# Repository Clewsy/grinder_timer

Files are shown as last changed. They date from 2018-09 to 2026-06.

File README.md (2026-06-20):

# grinder_timer

## Rev2.1

Modelled and printed a bezel for the OLED to tidy-up the enclosure.  Modelled in [freecad][link_web_freecad], printed on a [Prusa CORE One+][link_web_prusa].  CAD files and photo [here][link_repo_bezel].

## Rev2

More information can be found at my [project page][link_clews_grinder_timer_rev2].

Improvements since rev1:

- Hardware:
	- [X] Pull-ups on I2C SDA and CLK lines.
	- [X] Drive relay with a transistor instead of direct from IO.
	- [X] Add flyback diode protection to relay coil.
	- [X] Smaller transformer.
	- [X] Smaller relay.
	- [X] Switch to SMD where possible.
	- [X] Two-sided PCB (have it fabricated instead of etching).
	- [X] Switch buttons from mushy panel-mount to tactile SMD.
	- [X] Balanced caps for the 32.768kHz crystal.
	- [X] Put grind button LED on a PWM output.
- Firmware:
	- [X] Switch from C to C++.
	- [X] New OLED driver (change from SPI SSD1306 to I2C SH1106 controller).
	- [X] Pulse/fade effect for grind button LED.
	- [X] Ability to cancel a grind once started.
	- [X] Remember selected preset after a power-cycle.

Repo contents:
- [data][link_repo_data]: Datasheets and specs for the various components used.
- [firmware][link_repo_firmware]: The code witten in C++ and developed in VSCode with the PlatformIO IDE.
- [hardware][link_repo_hardware]: KiCad files including the [schematic][link_repo_schematic] and PCB layout.
- [rev1_archive][link_repo_rev1_archive]: Firmware developed for the original grinder_timer (written in C).

Note: I used an ATmega328PB which isn't supported by the latest avr-libc package.  For the code in this repo to compile, using the included makefile, options are:
a) Modify to use an ATmega328; or
b) Manually install the *libatmega328pb.a*, *iom328pb.h* and *crtatmega328pb.o* files; or
c) Use platformio instead of the makefile.

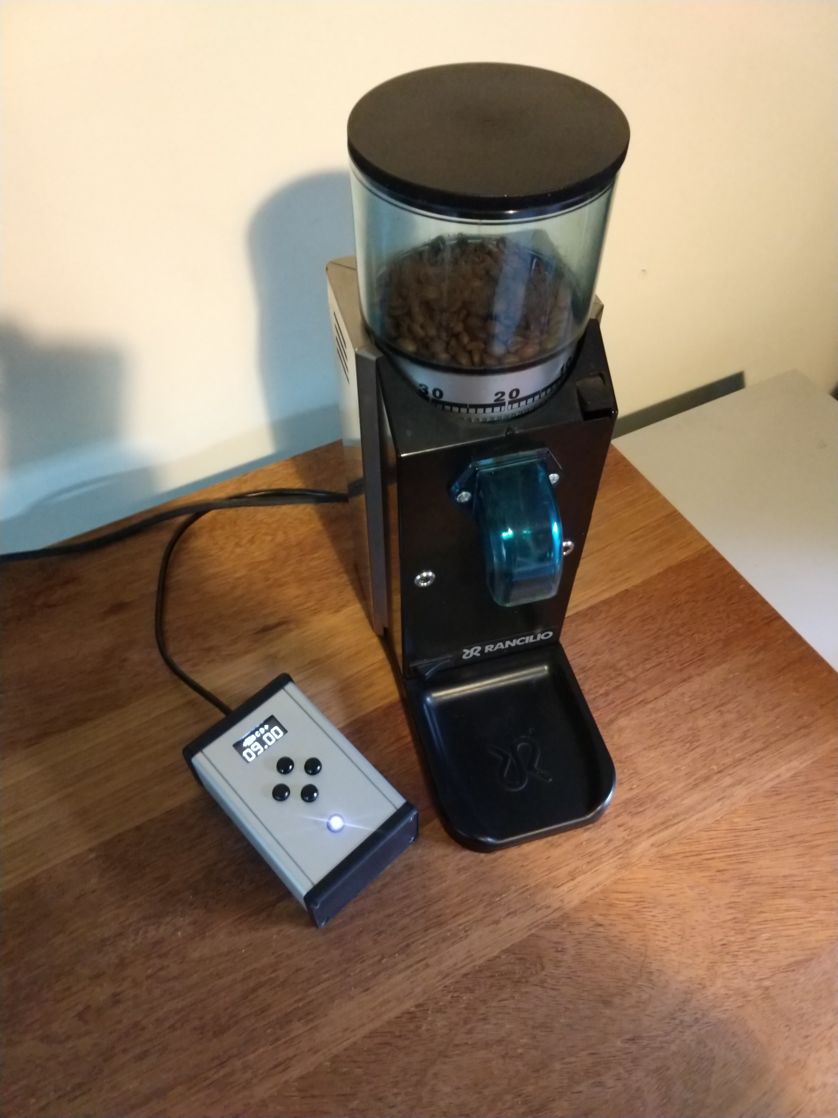
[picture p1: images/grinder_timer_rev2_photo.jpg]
The completed grinder_timer_rev2.

---

## Rev1

This is a programmable timer tethered to a [Rancilio Rocky][link_web_rancilio_rocky] coffee grinder. The Rocky is a "dumb" grinder and electrically very simple. Basically it's an ac motor with an on/off switch and a momentary push-button to grind. This project adds an electronic timer so that repeatable grind quantities can be produced without having to stand over the grinder. Features:
- Four programmable presets (A, B, C or D) stored in EEPROM to survive powercycle.
- Left/Right buttons to select preset.
- Up/Down buttons to adjust grind duration for selected preset (0.25s increments up to 60s).
- Grind button to initiate grind and begin countdown timer.
- Oled display (128x64) to show preset menu and countdown timer.
- Aluminium enclosure.
- Single cable (3-core) tether to grinder for power and control.

The code, schematic and PCB layout are all included here on gitlab.  More information can be found at my [project page][link_clews_grinder_timer].

Proudly mentioned at [hackaday.com][link_web_hackaday_grinder_timer].

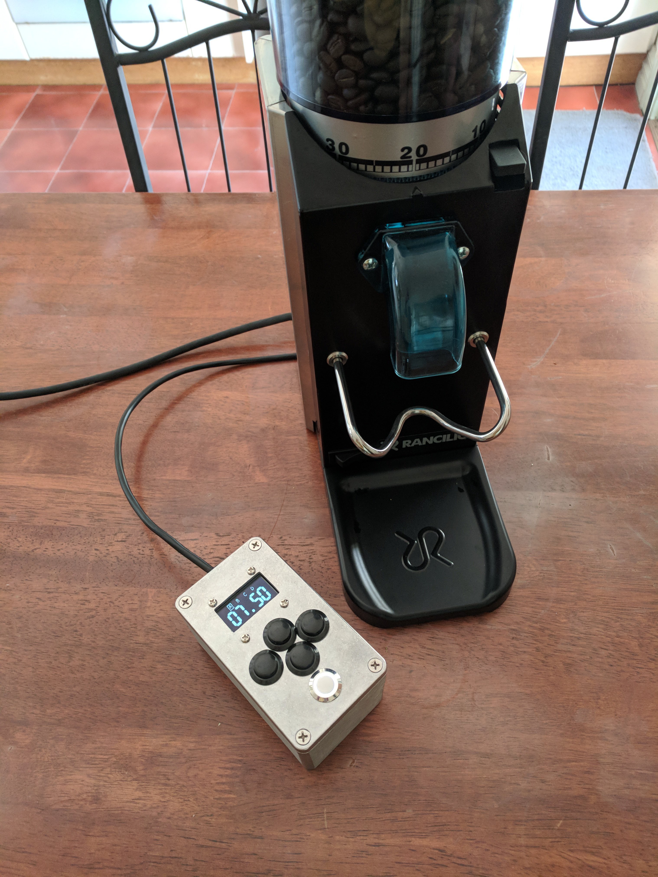
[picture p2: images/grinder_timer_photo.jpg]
The completed grinder_timer.


[link_clews_grinder_timer]:https://clews.pro/projects/grinder_timer.php
[link_clews_grinder_timer_rev2]:https://clews.pro/projects/grinder_timer_rev2.php

[link_repo_bezel]:hardware/bezel/
[link_repo_data]:data/
[link_repo_firmware]:firmware/
[link_repo_hardware]:hardware/pcb/
[link_repo_rev1_archive]:rev1_archive/
[link_repo_schematic]:hardware/schematic.pdf

[link_web_freecad]:https://www.freecad.org/
[link_web_hackaday_grinder_timer]:https://hackaday.com/2017/12/14/dumb-coffee-grinder-gets-smarter-with-time/
[link_web_prusa]:https://www.prusa3d.com/
[link_web_rancilio_rocky]:https://www.ranciliogroup.com/rancilio/rocky/rocky/

[image_grinder_timer]:images/grinder_timer_photo.jpg
[image_grinder_timer_rev2]:images/grinder_timer_rev2_photo.jpg

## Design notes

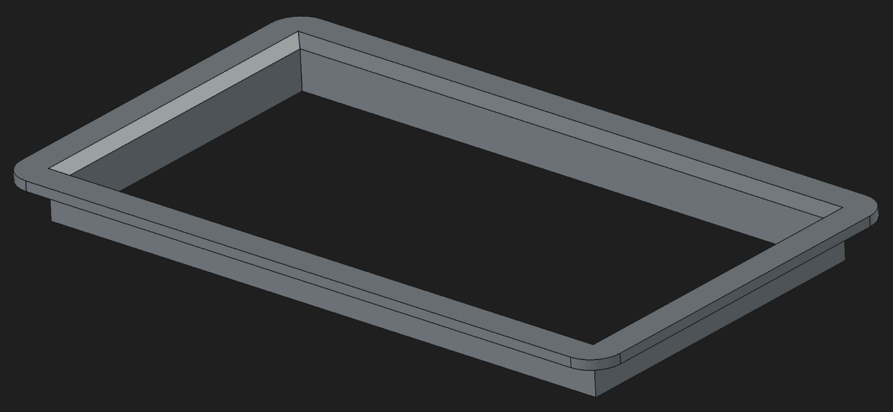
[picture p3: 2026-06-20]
hardware/bezel/grinder_timer_bezel_model.png

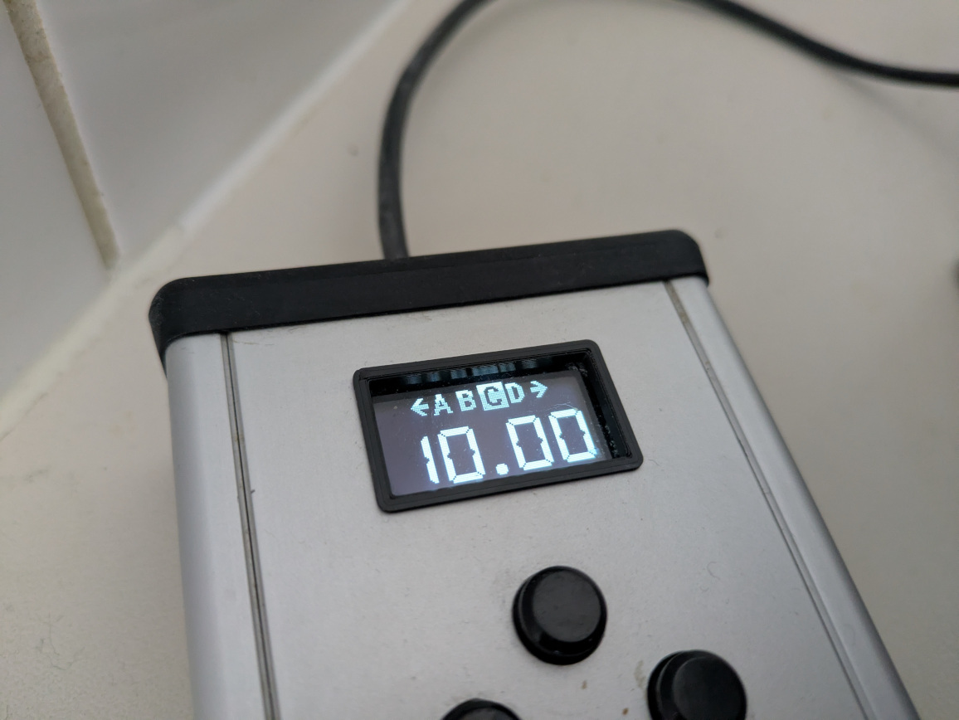
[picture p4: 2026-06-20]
hardware/bezel/grinder_timer_bezel.jpg

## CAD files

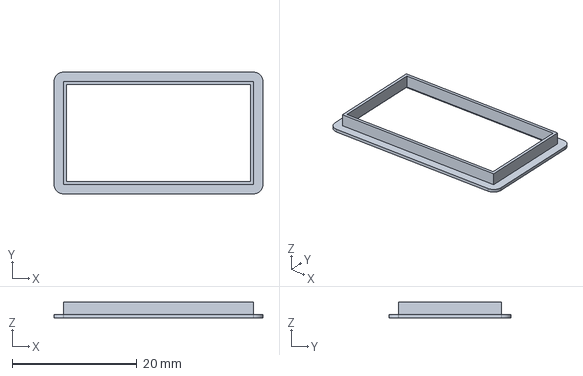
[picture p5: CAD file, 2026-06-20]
hardware/bezel/grinder_timer_bezel.FCStd
33.5 x 19.5 x 2.50 mm

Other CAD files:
hardware/bezel/grinder_timer_bezel.stl

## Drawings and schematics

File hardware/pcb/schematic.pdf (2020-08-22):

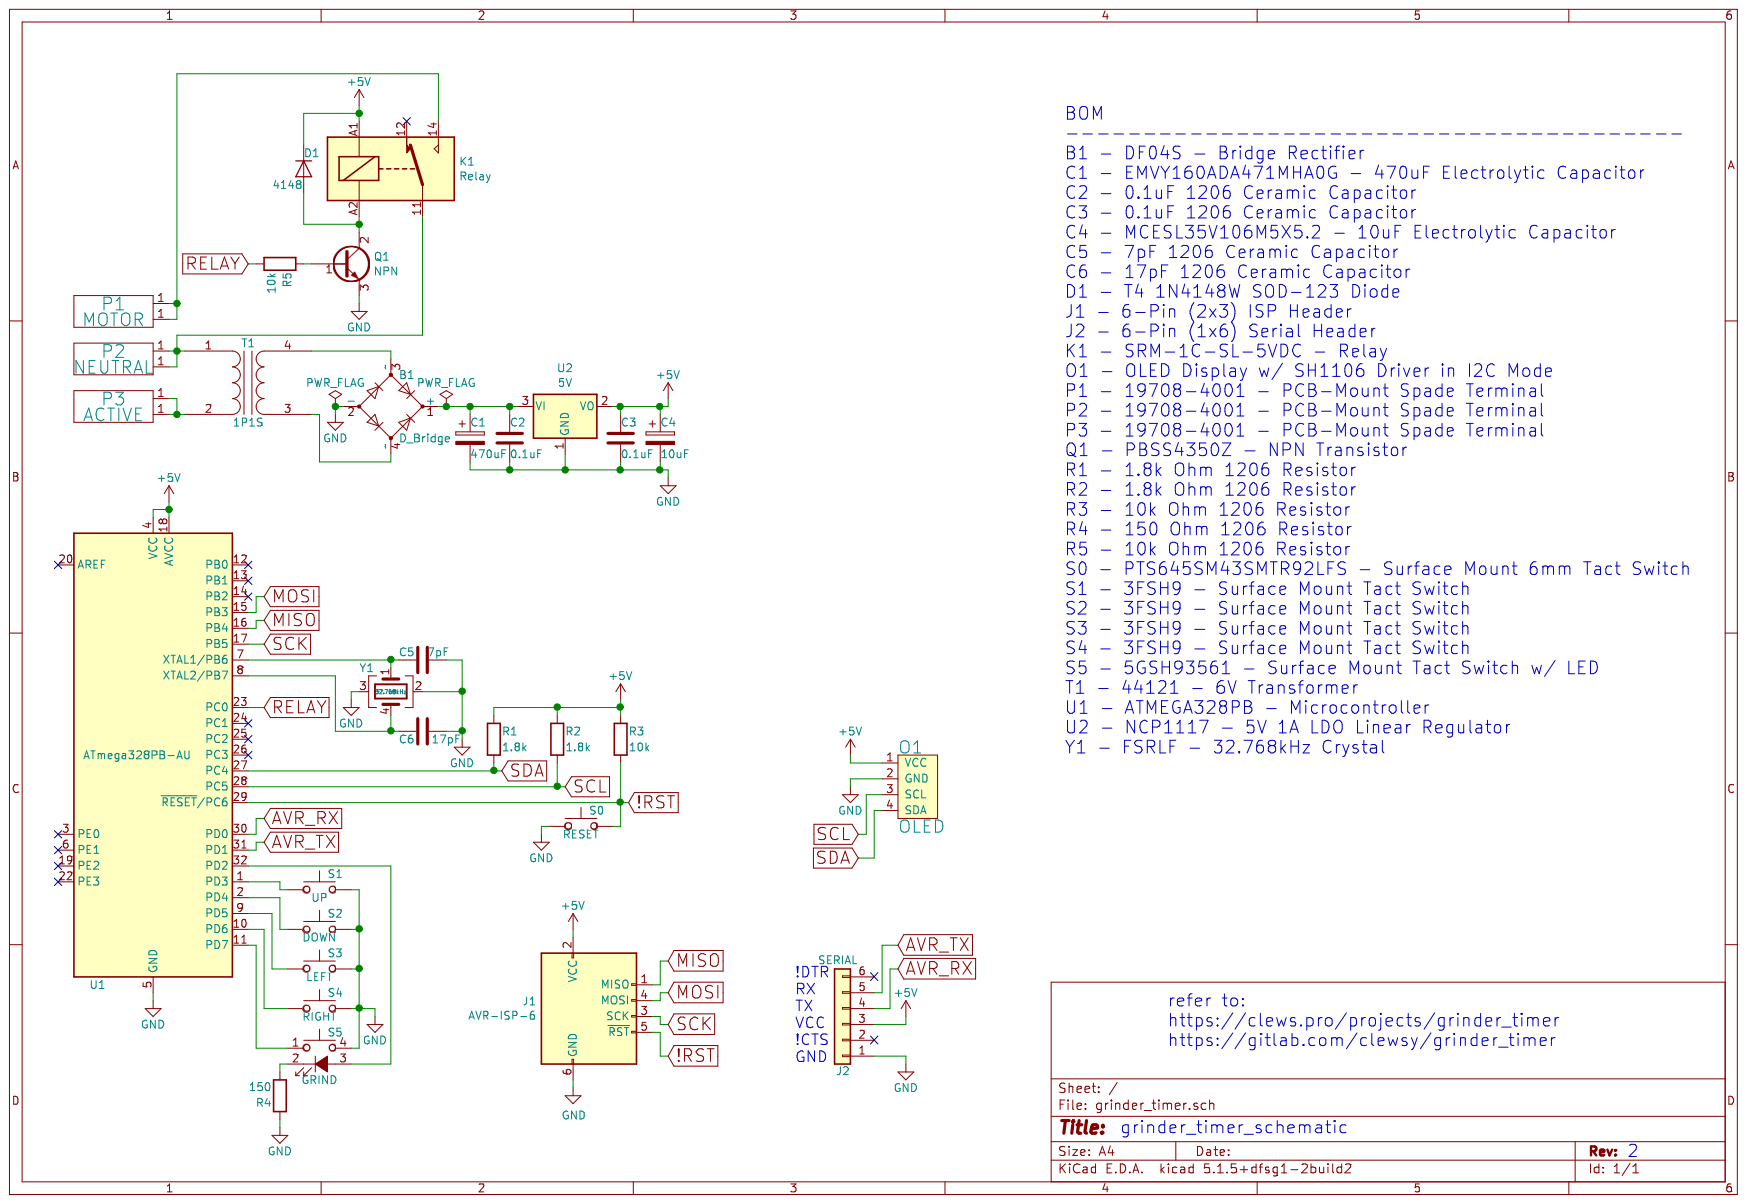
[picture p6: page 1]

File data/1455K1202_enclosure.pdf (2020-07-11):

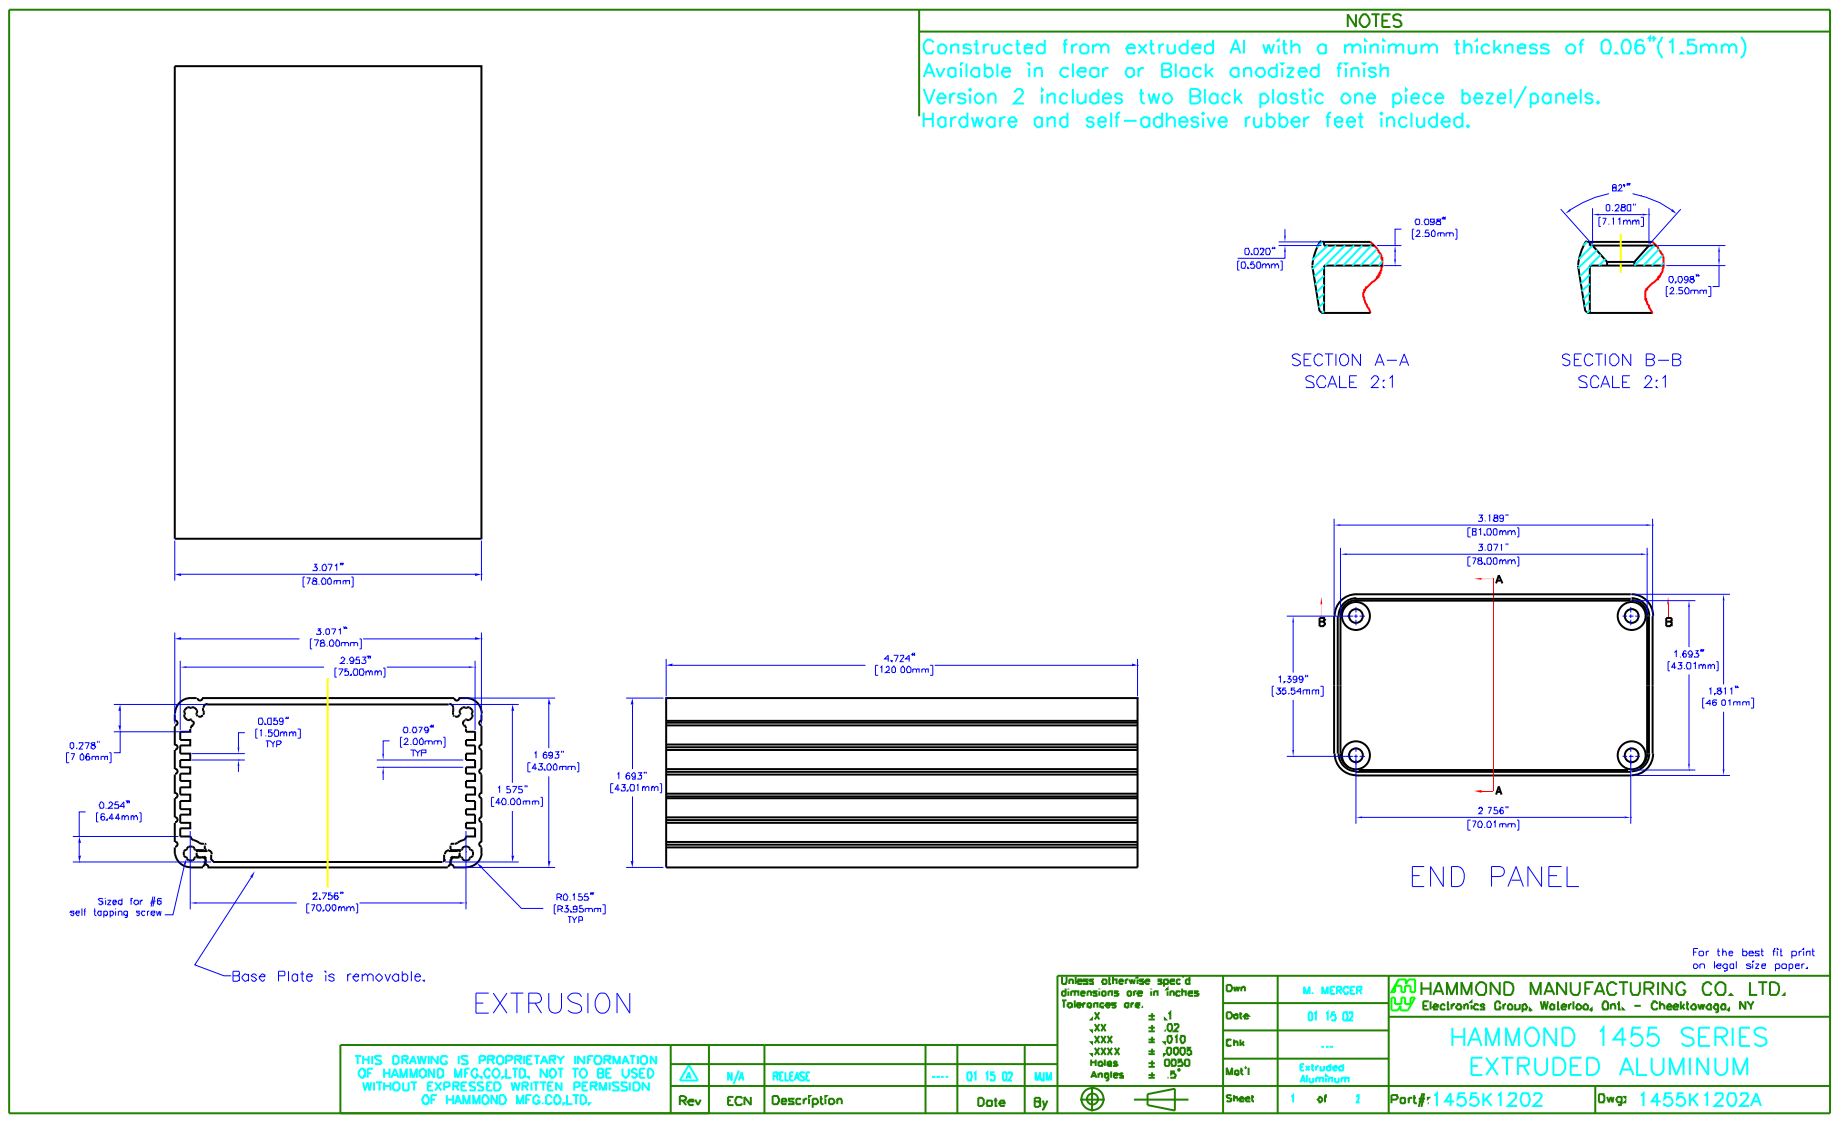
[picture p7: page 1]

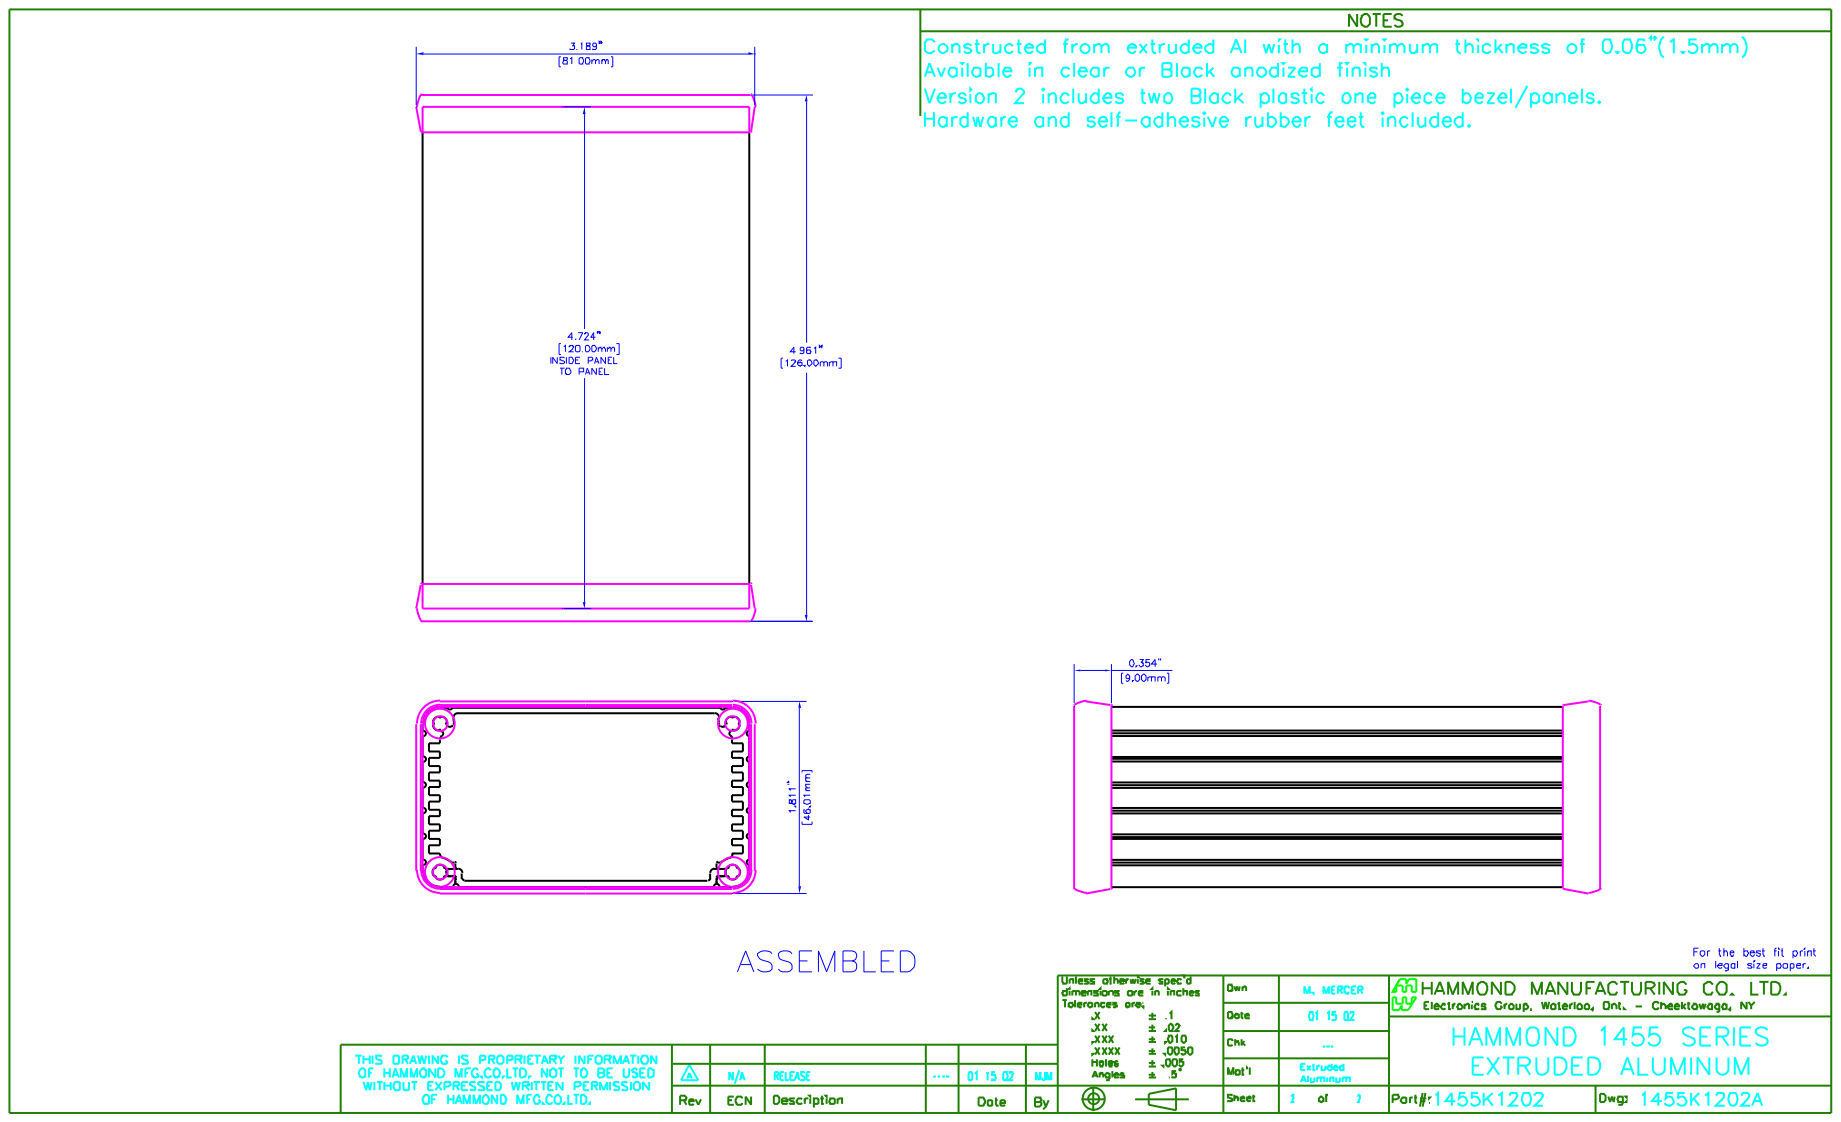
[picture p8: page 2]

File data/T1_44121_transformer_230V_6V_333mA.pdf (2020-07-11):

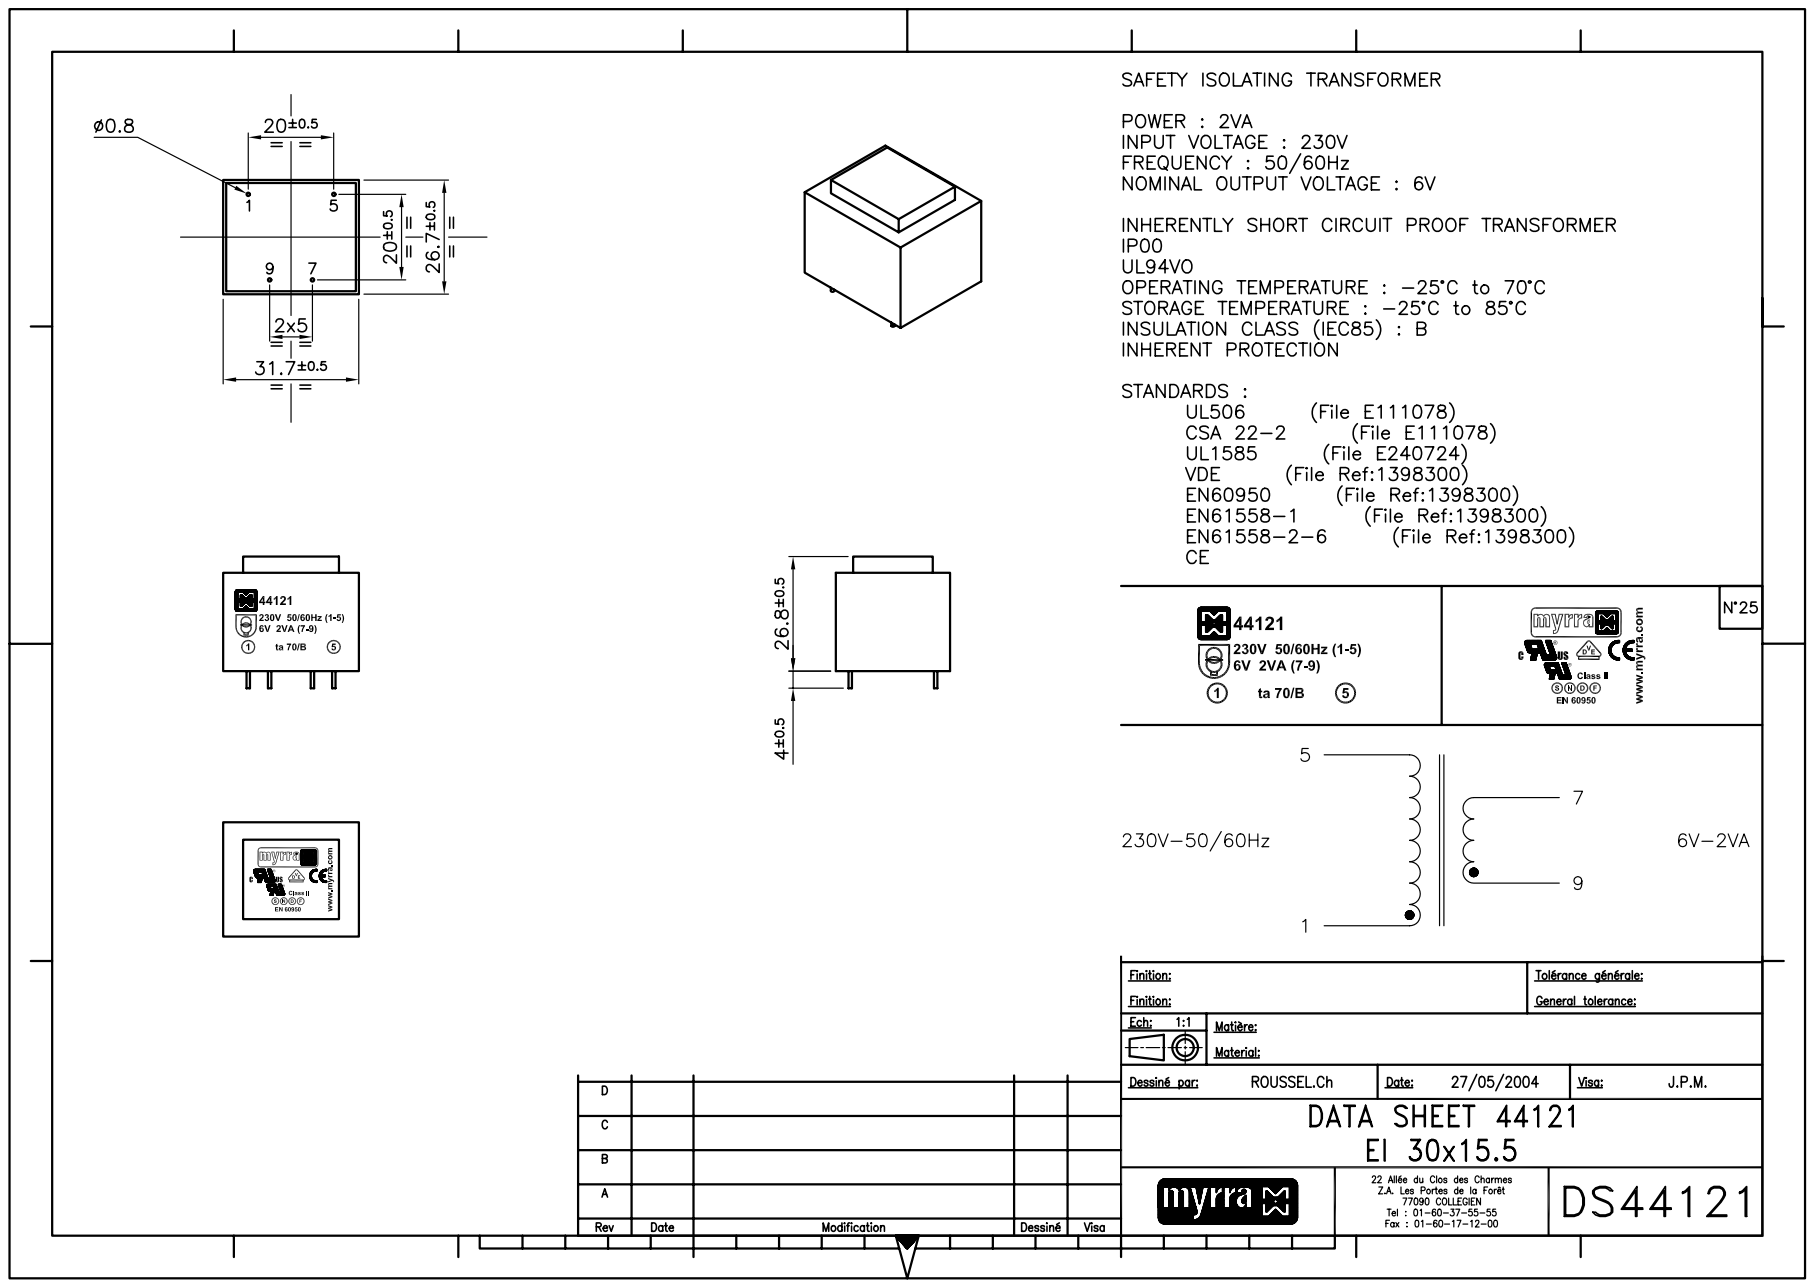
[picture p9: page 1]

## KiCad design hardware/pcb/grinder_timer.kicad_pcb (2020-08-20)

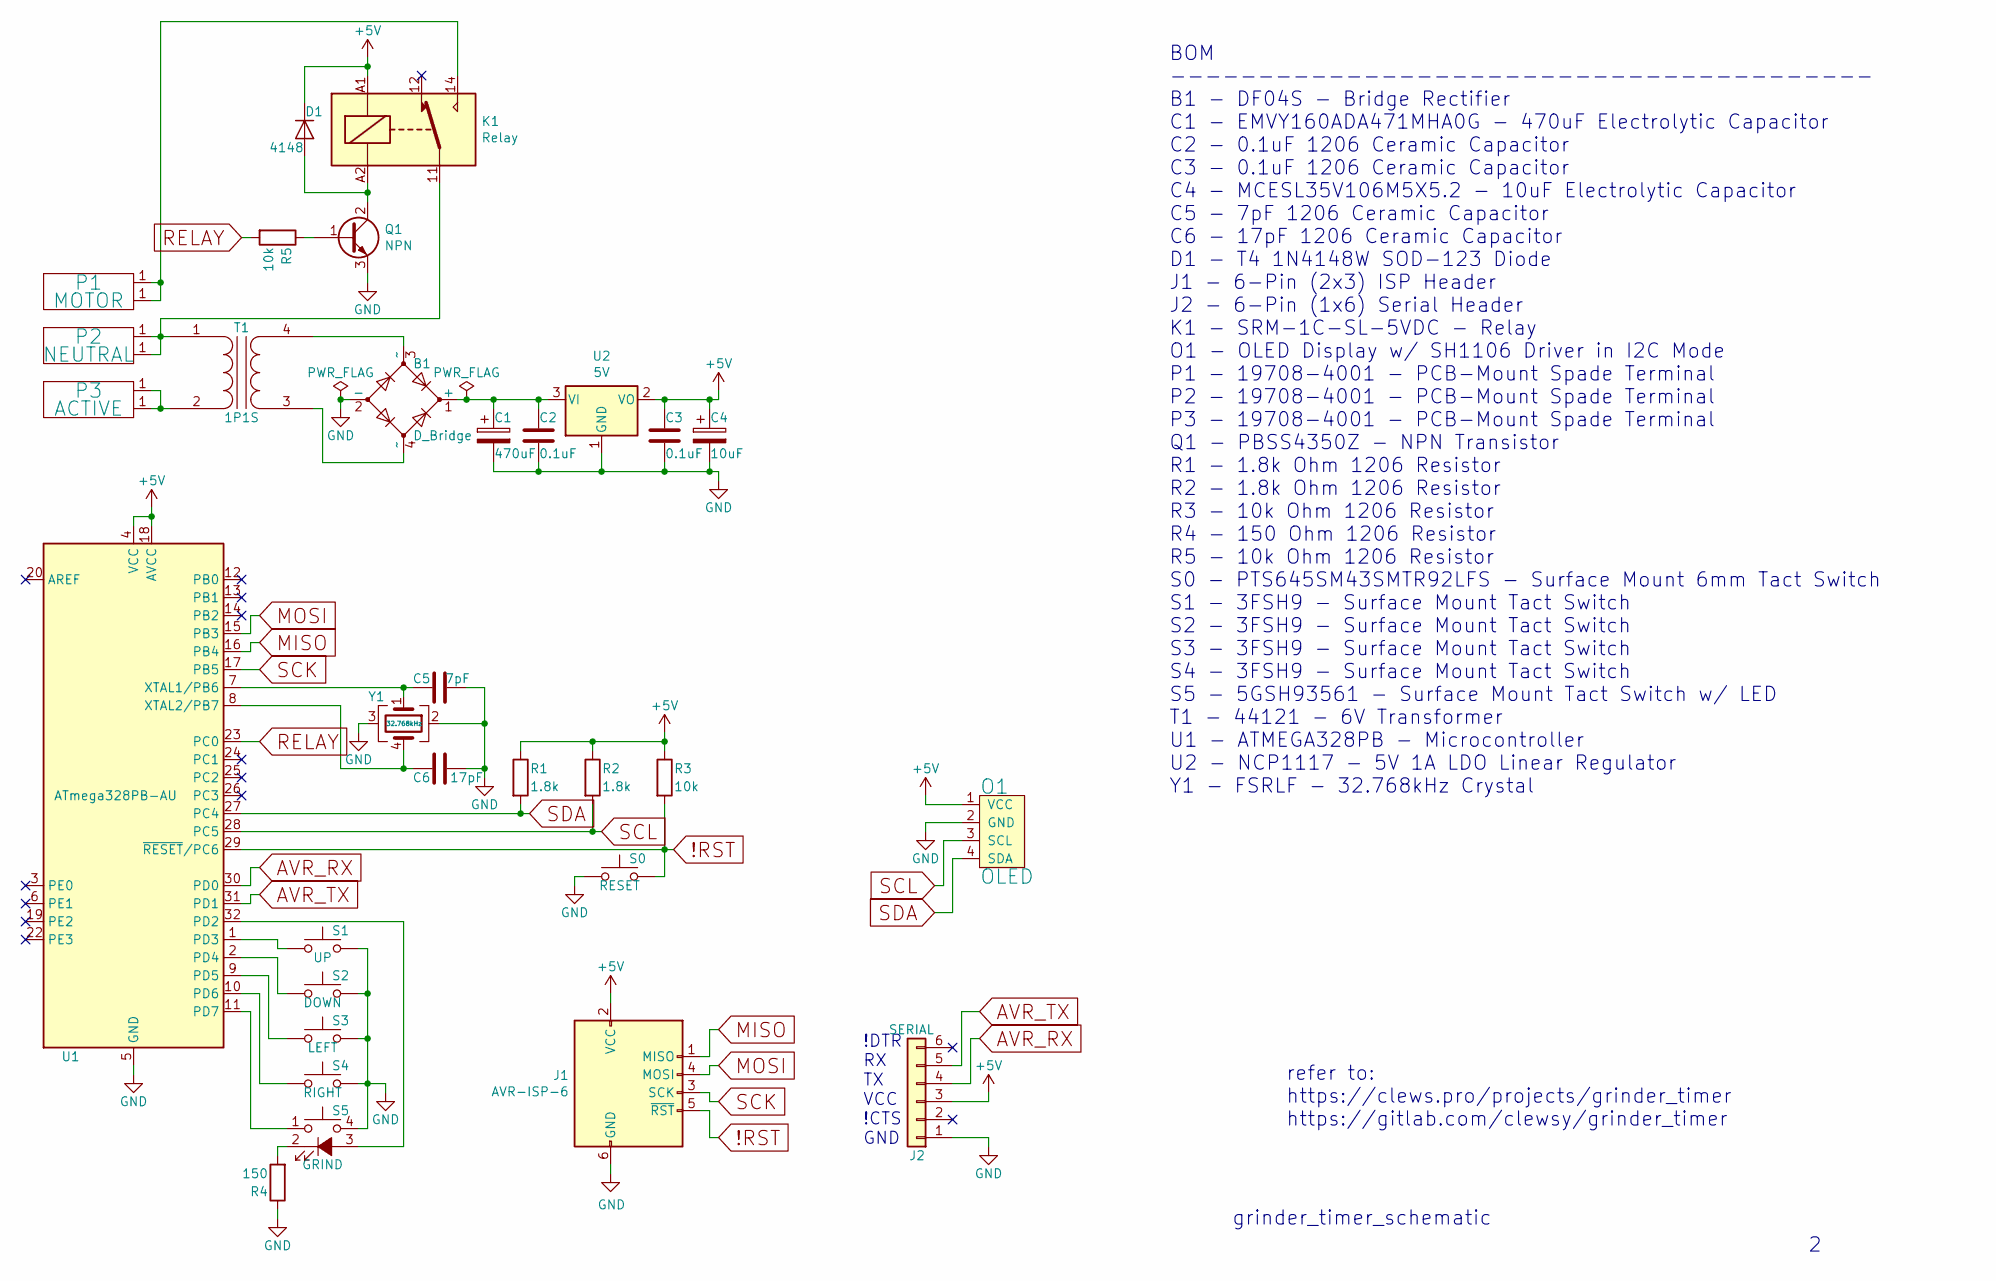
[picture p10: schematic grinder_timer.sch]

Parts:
B1: D_Bridge; Diode_Bridge_Vishay_DFS
C1: 470uF; C_Elec_8x10.2
C2, C3: 0.1uF; C_1206_3216Metric_Pad1.42x1.75mm_HandSolder
C4: 10uF; C_Elec_5x5.4
C5: 7pF; C_1206_3216Metric_Pad1.42x1.75mm_HandSolder
C6: 17pF; C_1206_3216Metric_Pad1.42x1.75mm_HandSolder
D1: 4148; D_SOD-123
J1: AVR-ISP-6; IDC-Header_2x03_P2.54mm_Vertical
J2: SERIAL; PinHeader_1x06_P2.54mm_Vertical
K1: Relay; Relay_SPDT_Finder_36.11
O1: OLED; oled
P1: MOTOR; pcb_tab
P2: NEUTRAL; pcb_tab
P3: ACTIVE; pcb_tab
Q1: NPN; SOT-223-3_TabPin2
R1, R2: 1.8k; R_1206_3216Metric_Pad1.42x1.75mm_HandSolder
R3, R5: 10k; R_1206_3216Metric_Pad1.42x1.75mm_HandSolder
R4: 150; R_1206_3216Metric_Pad1.42x1.75mm_HandSolder
S0: RESET; SW_Push_1P1T_NO_6x6mm_H9.5mm
S1: UP; tact
S2: DOWN; tact
S3: LEFT; tact
S4: RIGHT; tact
S5: GRIND; tact_led
T1: 1P1S; transformer_big
U1: ATmega328PB-AU; TQFP-32_7x7mm_P0.8mm
U2: 5V; SOT-223-3_TabPin2
Y1: 32.768kHz; Crystal_SMD_Abracon_ABS25-4Pin_8.0x3.8mm

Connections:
!RST: J1.5 (~RST), R3.2, S0.2, U1.29 (~RESET~/PC6)
+5V: C3.1, C4.1, D1.1 (K), J1.2 (VCC), J2.3, K1.A1, O1.1 (VCC), R1.1, R2.1, R3.1, U1.4 (VCC), U1.18 (AVCC), U2.2 (VO)
AVR_RX: J2.4, U1.30 (PD0)
AVR_TX: J2.5, U1.31 (PD1)
GND: B1.2 (-), C1.2, C2.2, C3.2, C4.2, C5.1, C6.1, J1.6 (GND), J2.1, O1.2 (GND), Q1.3 (E), R4.1, S0.1, S1.2, S2.2, S3.2, S4.2, S5.4 (A), U1.5 (GND), U1.21 (GND), U2.1 (GND), Y1.2, Y1.3
MISO: J1.1 (MISO), U1.16 (PB4)
MOSI: J1.4 (MOSI), U1.15 (PB3)
unnamed: B1.1 (+), C1.1, C2.1, U2.3 (VI)
unnamed: B1.3 (~~), T1.4 (SB)
unnamed: B1.4 (~~), T1.3 (SA)
unnamed: C5.2, U1.7 (XTAL1/PB6), Y1.1
unnamed: C6.2, U1.8 (XTAL2/PB7), Y1.4
unnamed: D1.2 (A), K1.A2, Q1.2 (C)
unnamed: K1.11, P2.1, T1.1 (AA)
unnamed: K1.14, P1.1
unnamed: P3.1, T1.2 (AB)
unnamed: Q1.1 (B), R5.1
unnamed: R4.2, S5.2
unnamed: S1.1, U1.1 (PD3)
unnamed: S2.1, U1.2 (PD4)
unnamed: S3.1, U1.9 (PD5)
unnamed: S4.1, U1.10 (PD6)
unnamed: S5.1, U1.11 (PD7)
unnamed: S5.3 (K), U1.32 (PD2)
RELAY: R5.2, U1.23 (PC0)
SCK: J1.3 (SCK), U1.17 (PB5)
SCL: O1.3 (SCL), R2.2, U1.28 (PC5)
SDA: O1.4 (SDA), R1.2, U1.27 (PC4)

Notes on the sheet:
refer to: https://clews.pro/projects/grinder_timer https://gitlab.com/clewsy/grinder_timer
grinder_timer_schematic
!DTR RX TX VCC !CTS GND
BOM ---------------------------------------- B1 - DF04S - Bridge Rectifier C1 - EMVY160ADA471MHA0G - 470uF Electrolytic Capacitor C2 - 0.1uF 1206 Ceramic Capacitor C3 - 0.1uF 1206 Ceramic Capacitor C4 - MCESL35V106M5X5.2 - 10uF Electrolytic Capacitor C5 - 7pF 1206 Ceramic Capacitor C6 - 17pF 1206 C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

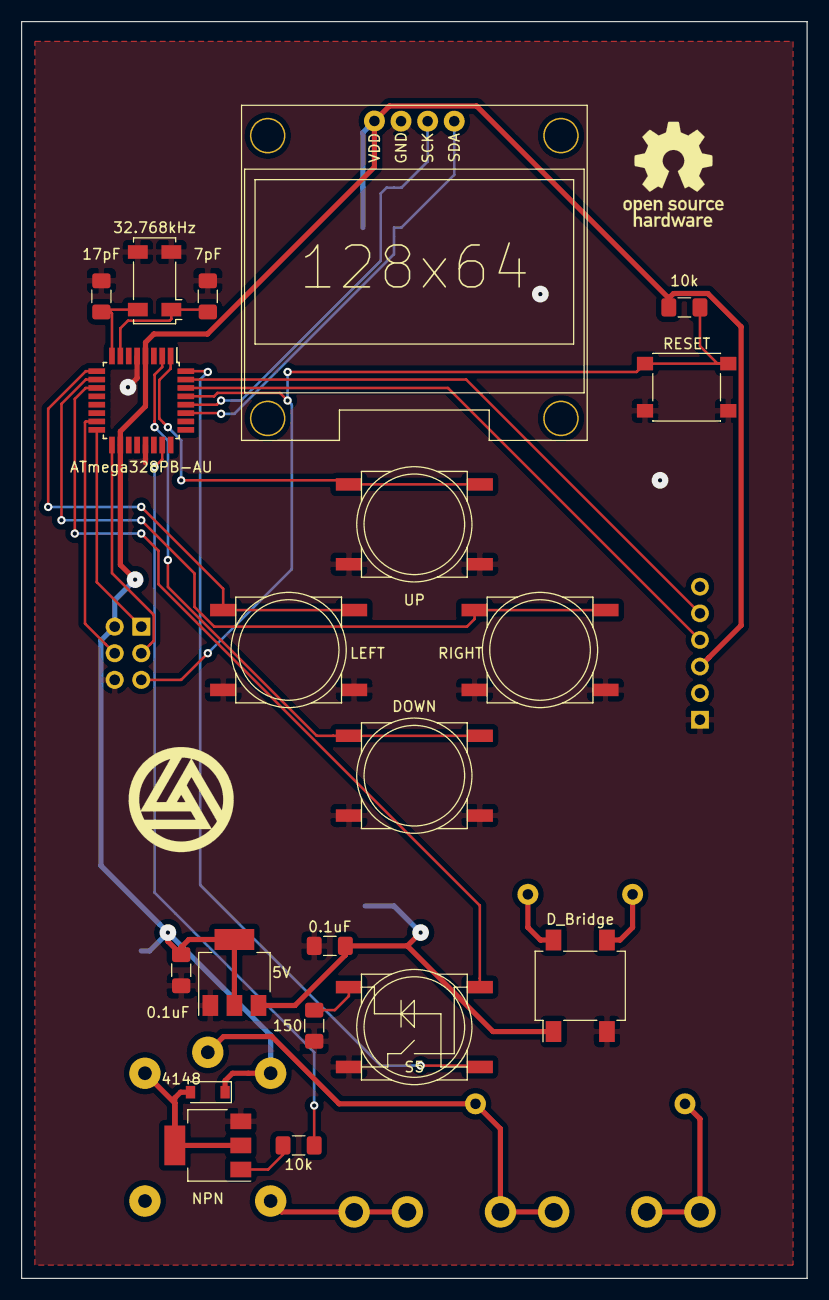
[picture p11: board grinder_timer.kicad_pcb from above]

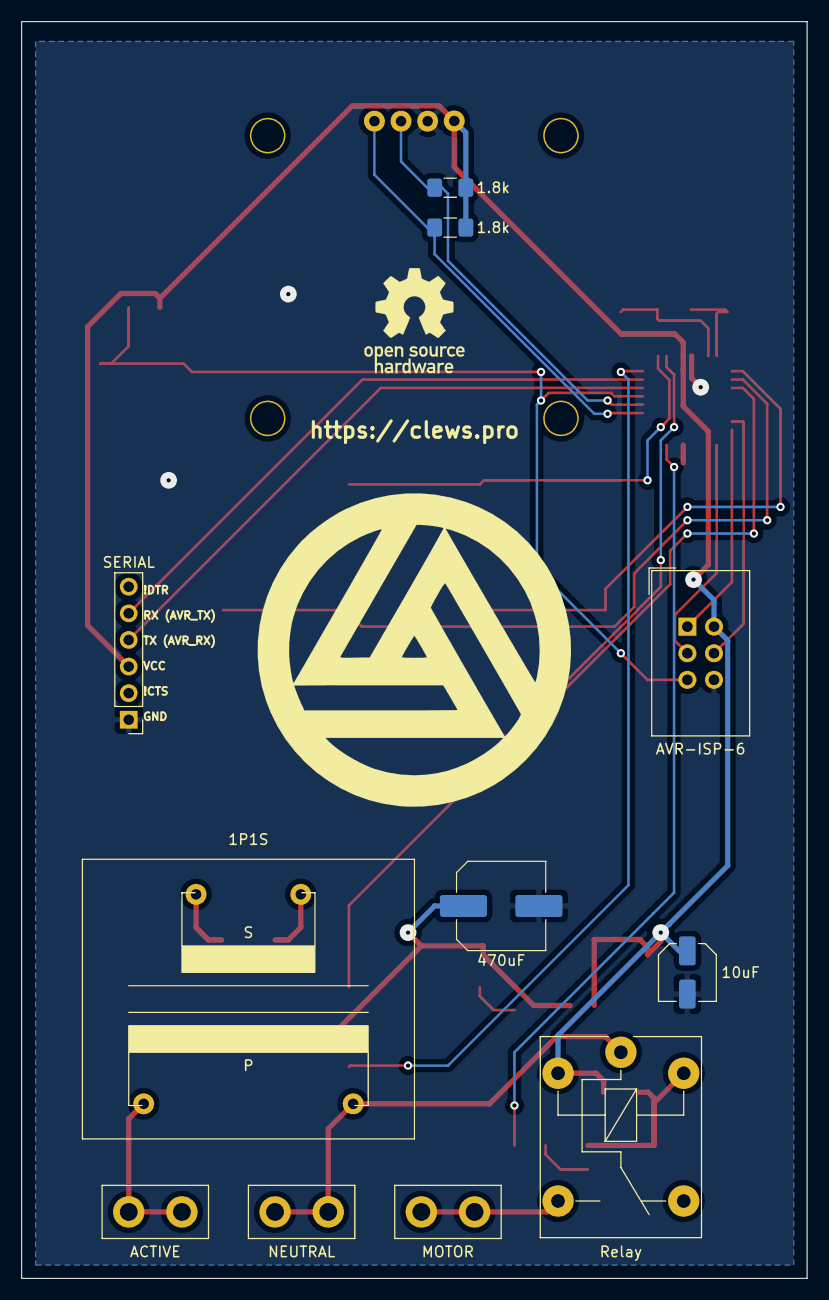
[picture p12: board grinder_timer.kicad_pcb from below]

Board: 2 copper layers, 75.0 x 120.0 mm, 31 parts (11 on the bottom side), 28 nets.

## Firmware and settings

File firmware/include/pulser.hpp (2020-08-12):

// Header file to define a generic hardware timer that triggers an interrupt sub-routine.

#include <avr/io.h>
#include <avr/interrupt.h>	// For using interrupt sub-routine vectors.

// Definitions used for initiatilising and controling the pulse timer. 
#define PULSER_TCCRA		TCCR1A			// Timer/Counter Control Register A
#define PULSER_TCCRB		TCCR1B			// Timer/Counter Control Register B
#define PULSER_WGM3		WGM13			// Timer/Counter Waveform Generation Mode Bit 3
#define PULSER_WGM2		WGM12			// Timer/Counter Waveform Generation Mode Bit 2
#define PULSER_WGM1		WGM11			// Timer/Counter Waveform Generation Mode Bit 1
#define PULSER_WGM0		WGM10			// Timer/Counter Waveform Generation Mode Bit 0
#define PULSER_CS2		CS12			// Timer/Counter Clock Select Bit 2
#define PULSER_CS1		CS11			// Timer/Counter Clock Select Bit 1
#define PULSER_CS0		CS10			// Timer/Counter Clock Select Bit 0
#define PULSER_SET_REG		OCR1A			// Timer/Counter Output Compare Register
#define PULSER_TIMSK		TIMSK1			// Timer/Counter Timer Interrupt Mask Register
#define PULSER_IE		OCIE1A			// Timer Output Compare Interrupt Enable Bit.
#define PULSER_INT_VECTOR	TIMER1_COMPA_vect	// Interrupt subroutine name.
#define PULSER_SPEED		8000			// Write to PULSER_SET_REG to set the pulse speed.

// Definitions used for initiatilising and controling the pwm timer. 
#define PWM_PIN			PD2			// In PWM mode, using PD3 as OC3B.
#define PWM_PORT		PORTD			// IO Port that includes the PWM pin.
#define PWM_DDR			DDRD			// Data Direction Register that includes DDR for the PWM pin.
#define PWM_SET			OCR3B			// Output compare register (writing 8-bits to here sets the pulse-width).
#define PWM_TCCRA		TCCR3A			// Timer/Counter Control Register
#define PWM_TCCRB		TCCR3B			// Timer/Counter Control Register
#define PWM_COM0		COM3B0			// Compare Output Mode Bit 0
#define PWM_COM1		COM3B1			// Compare Output Mode Bit 1
#define PWM_WGM0		WGM30			// Waveform Generation Mode Bit 0
#define PWM_WGM1		WGM31			// Waveform Generation Mode Bit 1
#define PWM_WGM2		WGM32			// Waveform Generation Mode Bit 2
#define PWM_WGM3		WGM33			// Waveform Generation Mode Bit 3
#define PWM_CS0			CS30			// Clock Select Bit 0
#define PWM_CS1			CS31			// Clock Select Bit 1
#define PWM_CS2			CS32			// Clock Select Bit 2

// Definitions used by the mode() function.
#define LED_OFF			0b00			// Set LED to off.
#define LED_ON			0b01			// Set LED to on.
#define LED_PULSE		0b11			// Set LED to pulsing.
#define LED_MAX_BRIGHTNESS	150			// Sets the max brightness of the LED when pulsing or on (pwm pulse-width 0 to 255).


class pulser
{
	public:
		void init(uint8_t initial_mode);
		void mode(uint8_t mode);
		void interrupt_handler(void);
	private:
		void enable_pwm(bool enable);
		void enable_pulse(bool enable);
		void set_pwm(uint8_t duty);
		uint8_t get_pwm(void);
		int8_t direction = 1;	// Enables tracking of the LED pulse effect, i.e. 1:getting brighter, -1:getting dimmer.
};

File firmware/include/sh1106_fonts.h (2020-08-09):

// Addresses (byte number) within font maps of important font metadata.
#define FONT_WIDTH	0	// First byte defines the font width in pixels.  This is maximum width for non-fixed-width fonts.
#define FONT_HEIGHT	1	// Second byte defines the height in pixels of all characters.
#define FONT_FIRST_CHAR	2	// Third byte defines the first ascii character contained within the font map.  Often ' ' (space).
#define FONT_NUM_CHARS	3	// Fourth byte defines the total number of characters mapped within the font.
#define FIRST_CHAR_META	4	// Fifth byte is the first character metadata byte.  I.e. first byte of jump table.

// Addresses (byte number) within the metadata bytes for each character.
#define CHAR_ADDR_MSB	0	// First character metadata byte defines the MSB of the character data map address.
#define CHAR_ADDR_LSB	1	// Second character metadata byte defines the LSB of the character data map address.
#define CHAR_BYTE_SIZE	2	// Third character metadata byte defines the size (in bytes) of the character data.
#define CHAR_WIDTH	3	// Fourth character metadata byte defines the width (in pixels) of the character.


// The fonts used in this file were generated at: http://oleddisplay.squix.ch/ 
// Consider a donation.

const uint8_t Roboto_Mono_12[] PROGMEM = {
	0x07, // Width: 7
	0x0F, // Height: 15
	0x20, // First Char: 32
	0x60, // Numbers of Chars: 96

// Jump table - contains metadata for individual characters.
//	 +-----------------------MSB of character data address.
//	 |     +-----------------LSB of character data address.
//	 |     |     +-----------Number of data bytes used for the character.
//	 |     |     |     +-----Width in pixels of the character.
//	 |     |     |     |
	0xFF, 0xFF, 0x00, 0x07,  // 32:65535	' '
	0x00, 0x00, 0x08, 0x07,  // 33:0	'!'
	0x00, 0x08, 0x09, 0x07,  // 34:8	'"'
	0x00, 0x11, 0x0D, 0x07,  // 35:17	'#'
	0x00, 0x1E, 0x0C, 0x07,  // 36:30	'$'
	0x00, 0x2A, 0x0E, 0x07,  // 37:42	'%'
	0x00, 0x38, 0x0E, 0x07,  // 38:56	'^'
	0x00, 0x46, 0x07, 0x07,  // 39:70	'''
	0x00, 0x4D, 0x0A, 0x07,  // 40:77	'('
	0x00, 0x57, 0x0A, 0x07,  // 41:87	')'
	0x00, 0x61, 0x0D, 0x07,  // 42:97	'*'
	0x00, 0x6E, 0x0D, 0x07,  // 43:110	'+'
	0x00, 0x7B, 0x08, 0x07,  // 44:123	','
	0x00, 0x83, 0x0B, 0x07,  // 45:131	'-'
	0x00, 0x8E, 0x0A, 0x07,  // 46:142	'.'
	0x00, 0x98, 0x0B, 0x07,  // 47:152	'/'
	0x00, 0xA3, 0x0C, 0x07,  // 48:163	'0'
	0x00, 0xAF, 0x0A, 0x07,  // 49:175	'1'
	0x00, 0xB9, 0x0C, 0x07,  // 50:185	'2'
	0x00, 0xC5, 0x0C, 0x07,  // 51:197	'3'
	0x00, 0xD1, 0x0E, 0x07,  // 52:209	'4'
	0x00, 0xDF, 0x0C, 0x07,  // 53:223	'5'
	0x00, 0xEB, 0x0C, 0x07,  // 54:235	'6'
	0x00, 0xF7, 0x0B, 0x07,  // 55:247	'7'
	0x01, 0x02, 0x0C, 0x07,  // 56:258	'8'
	0x01, 0x0E, 0x0C, 0x07,  // 57:270	'9'
	0x01, 0x1A, 0x0A, 0x07,  // 58:282	':'
	0x01, 0x24, 0x0A, 0x07,  // 59:292	';'
	0x01, 0x2E, 0x0C, 0x07,  // 60:302	'<'
	0x01, 0x3A, 0x0C, 0x07,  // 61:314	'='
	0x01, 0x46, 0x0C, 0x07,  // 62:326	'>'
	0x01, 0x52, 0x0B, 0x07,  // 63:338	'?'
	0x01, 0x5D, 0x0E, 0x07,  // 64:349	'@'
	0x01, 0x6B, 0x0E, 0x07,  // 65:363	'A'
	0x01, 0x79, 0x0E, 0x07,  // 66:377	'B'
	0x01, 0x87, 0x0E, 0x07,  // 67:391	'C'
	0x01, 0x95, 0x0E, 0x07,  // 68:405	'D'
	0x01, 0xA3, 0x0C, 0x07,  // 69:419	'E'
	0x01, 0xAF, 0x0B, 0x07,  // 70:431	'F'
	0x01, 0xBA, 0x0E, 0x07,  // 71:442	'G'
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
	0xFF, 0xFF, 0x00, 0x07,  // 127:65535	DEL

	// Font Data:
	0x00,0x00,0x00,0x00,0x00,0x00,0xF8,0x09,	// 33
	0x00,0x00,0x00,0x00,0x1C,0x00,0x00,0x00,0x1C,	// 34
	0x00,0x01,0x20,0x0D,0xE0,0x03,0x38,0x01,0xA0,0x0F,0x78,0x01,0x20,	// 35
	0x00,0x00,0x30,0x06,0x68,0x0C,0xC6,0x18,0x84,0x08,0x98,0x07,	// 36
	0x30,0x00,0x48,0x00,0x78,0x06,0x80,0x01,0x60,0x0F,0x10,0x09,0x00,0x0E,	// 37
	0x00,0x00,0x30,0x0F,0xD8,0x08,0xC8,0x09,0x78,0x0A,0x00,0x0E,0x00,0x09,	// 38
	0x00,0x00,0x00,0x00,0x00,0x00,0x1C,	// 39
	0x00,0x00,0x00,0x00,0xC0,0x07,0x30,0x18,0x0C,0x60,	// 40
	0x00,0x00,0x00,0x00,0x0C,0x60,0x30,0x18,0xC0,0x0F,	// 41
	0x00,0x00,0x40,0x00,0x40,0x03,0xF0,0x00,0x40,0x01,0x40,0x02,0x40,	// 42
	0x00,0x00,0x80,0x00,0x80,0x00,0xF0,0x07,0x80,0x00,0x80,0x00,0x80,	// 43
	0x00,0x00,0x00,0x00,0x00,0x20,0x00,0x18,	// 44
	0x00,0x00,0x80,0x00,0x80,0x00,0x80,0x00,0x80,0x00,0x80,	// 45
	0x00,0x00,0x00,0x00,0x00,0x00,0x00,0x0C,0x00,0x08,	// 46
	0x00,0x00,0x00,0x10,0x00,0x1C,0x80,0x03,0x70,0x00,0x08,	// 47
	0x00,0x00,0xF0,0x07,0x08,0x09,0x88,0x08,0x48,0x08,0xF0,0x07,	// 48
	0x00,0x00,0x10,0x00,0x10,0x00,0xF8,0x0F,0xF8,0x0F,	// 49
	0x00,0x00,0x30,0x0C,0x08,0x0A,0x08,0x09,0x98,0x08,0x70,0x08,	// 50
	0x00,0x00,0x10,0x04,0x88,0x08,0x88,0x08,0xD8,0x08,0x70,0x07,	// 51
	0x00,0x02,0x00,0x03,0xC0,0x02,0x30,0x02,0xF8,0x0F,0x00,0x02,0x00,0x02,	// 52
	0x00,0x00,0x40,0x06,0xF8,0x0C,0x48,0x08,0x48,0x08,0x88,0x07,	// 53
	0x00,0x00,0xE0,0x07,0x50,0x08,0x48,0x08,0x48,0x08,0x80,0x07,	// 54
	0x00,0x00,0x08,0x00,0x08,0x0C,0x08,0x07,0xC8,0x00,0x38,	// 55
	0x00,0x00,0x70,0x07,0xD8,0x08,0x88,0x08,0x88,0x08,0x70,0x07,	// 56
	0x00,0x00,0xF0,0x00,0x08,0x09,0x08,0x09,0x08,0x05,0xF0,0x03,	// 57
	0x00,0x00,0x00,0x00,0x00,0x00,0x60,0x0C,0x40,0x08,	// 58
	0x00,0x00,0x00,0x00,0x00,0x00,0x60,0x20,0x40,0x18,	// 59
	0x00,0x00,0x00,0x01,0x80,0x01,0x80,0x02,0x40,0x02,0x40,0x04,	// 60
	0x00,0x00,0x40,0x02,0x40,0x02,0x40,0x02,0x40,0x02,0x40,0x02,	// 61
	0x00,0x00,0x40,0x04,0x40,0x02,0x80,0x02,0x80,0x01,0x80,0x01,	// 62
	0x00,0x00,0x10,0x00,0x08,0x00,0x08,0x0B,0x88,0x00,0x70,	// 63
	0xC0,0x03,0x30,0x04,0xC8,0x0B,0x28,0x0A,0xE8,0x0B,0x10,0x02,0xE0,0x01,	// 64
	0x00,0x08,0x00,0x0E,0xE0,0x03,0x38,0x02,0xF0,0x02,0x00,0x07,0x00,0x08,	// 65
	0x00,0x00,0xF8,0x0F,0x88,0x08,0x88,0x08,0x88,0x08,0x70,0x0F,0x00,0x02,	// 66
	0x00,0x00,0xF0,0x07,0x08,0x08,0x08,0x08,0x08,0x08,0x30,0x06,0x20,0x02,	// 67
	0x00,0x00,0xF8,0x0F,0x08,0x08,0x08,0x08,0x08,0x08,0x30,0x06,0xC0,0x01,	// 68
	0x00,0x00,0xF8,0x0F,0x88,0x08,0x88,0x08,0x88,0x08,0x88,0x08,	// 69
	0x00,0x00,0xF8,0x0F,0x88,0x00,0x88,0x00,0x88,0x00,0x88,	// 70
	0x00,0x00,0xF0,0x07,0x08,0x0C,0x08,0x08,0x88,0x08,0x90,0x0F,0xA0,0x07,	// 71
	0x00,0x00,0xF8,0x0F,0x80,0x00,0x80,0x00,0x80,0x00,0xF8,0x0F,	// 72
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
};

const uint8_t DSEG7_Classic_Bold_32[] PROGMEM = {
	0x1A,	// Width: 26
	0x23,	// Height: 35
	0x20,	// First Char: 32
	0x1A,	// Numbers of Chars: 26
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

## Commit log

2017-11-13 Some basic i2c functionality and oled (SDD1306) control.
2017-11-14 Added SDD1306 driver with init and addressing functionality.
2017-11-15 Tidied driver files and added oled driver functions.
2017-11-16 Implemented an RTC on Timer/Counter2 (externally connected 32.768kHz crystal).
2017-11-17 Added character and string typing functionality to the oled driver.
2017-11-17 Modified time keeping operation. Added function to print byte to oled.
2017-11-17 Test circuit with LED on output. Added enable/disable functions for timer control.
2017-11-18 Implemented a hand-written 7-segment style numerical font. Unit works as a basic countdown timer.
2017-11-19 Minor code revisions. Now including schematic (kicad).
    [grinder_timer.kicad_pcb, grinder_timer.sch]
2017-11-20 Worked on the schematic and footprints.
    [grinder_timer.sch]
2017-11-21 Work on the schematic. Began PCB layout.
    [grinder_timer.kicad_pcb, grinder_timer.sch]
2017-11-22 PCB layout progress.
    [grinder_timer.kicad_pcb]
2017-11-23 Finished PCB layouts (first rev).
    [grinder_timer.kicad_pcb, grinder_timer.sch]
2017-11-25 Fixed a mis-wired push button on the schematic and PCB layout.
    [grinder_timer.kicad_pcb, grinder_timer.sch]
2017-11-26 First prototype PCB fabricated and somewhat successful. Major revision to improve.
    [grinder_timer.kicad_pcb, grinder_timer.sch]
2017-11-28 Minor changes - working on the hardware.
    [8x8_digits_font.xlsx]
2017-11-29 Added a capacitor across oled rest pin to simulate reset toggle on power-up.
    [grinder_timer.sch]
2017-12-01 Implemented a preset selection/adjustment menu system via four buttons.
    [preset_menu_font.xlsx]
2017-12-02 Implemented saving of presets to eeprom so as to survive powercycle.
2017-12-02 Fixed a glitch when resuming from oled sleep.
    [grinder_timer.c]
2017-12-03 Tidied code. Fixed skipped inc/dec of preset value if up/down button toggled rapidly.
    [grinder_timer.c, grinder_timer.h]
2017-12-04 Tidied schematic and pcb border.
    [grinder_timer.kicad_pcb, grinder_timer.sch]
2017-12-04 Added a reference schematic of the rancilio rocky coffee grinder.
    [grinder_timer.sch]
2017-12-04 Renamed file
    [24x48_digits_font.xlsx, 8x8_digits_font.xlsx]
2017-12-08 Code optimisation. Fixed a glitch that caused failure if buttons actuated during powerup.
    [grinder_timer.c, grinder_timer.h]
2017-12-12 Finished hardware mounting in enclosure. Opted to reverse orientation of OLED hence flipped in OLED init code.
2019-07-24 Added a pdf of the schematic.
2020-04-09 Repo restructure and readme overhaul.
    [24x48_digits_font.xlsx, preset_menu_font.xlsx]
2020-07-07 Begun rev_2 (schematic underway). Restructured repo.
    [grinder_timer.kicad_pcb, grinder_timer.sch]
2020-07-08 Working on rev_2 schematic.
    [grinder_timer.kicad_pcb, grinder_timer.sch]
2020-07-10 Added data, restructured schematic dir.
    [grinder_timer.kicad_pcb, grinder_timer.sch]
2020-07-10 Created custom footprints, assigned footprints to all symbols, began PCB layout.
    [grinder_timer.sch]
2020-07-11 Switched transformer. Completed PCB layout. Added silkscreen logos.
    [grinder_timer.kicad_pcb, grinder_timer.sch]
2020-07-19 Fixed let tact switch pinout. Modified via sizes.
    [grinder_timer.kicad_pcb, grinder_timer.sch]
2020-07-19 Generated gerber files for fab.
2020-07-28 Most parts have arrived. PCB mostly assembled. Testing inputs and outputs (buttons, LED and relay).
2020-08-02 Button interrupts working. Started looking at PWM output to LED.
2020-08-03 Got pwm output working.
2020-08-03 Implemented led pulse effect.
2020-08-04 Barely have the OLED working. Corrected the 5V regulator part on the schematic.
    [grinder_timer.h, i2c.cpp, keypad.h]
2020-08-04 OLED can print bitmaps. Slowed clock and I2C speeds for stability while I debug.
    [grinder_timer.sch]
2020-08-05 Lots of work, much improved i2c stability. Working OLED sh1106 drived. Added vertical scroll feature.
    [grinder_timer.h, i2c.cpp, sh1106_fonts.h]
2020-08-06 Tidied header file comments and fixed header file naming convention.
    [i2c.cpp, i2c.hpp, keypad.hpp]
2020-08-09 Added ability to cancel grinding by pressing any button while the motor is running.
2020-08-10 Implemented fast change of preset when the button is held. Could be more efficient.
2020-08-10 Cleaner left, right, up and down button handling.
2020-08-10 Much improved led control.
2020-08-11 General improvements. Added sleep mode timer.
2020-08-11 General improvements. Properly iomplemented sleep mode timer.
2020-08-12 Started working on preset timer retention in eeprom.
2020-08-12 Implemented retention of selected preset at power cycle.
2020-08-12 Merged led and pulser class, header and functions.
2020-08-12 Various improvements. Added a relay class. All desired features now present.
2020-08-13 I2C pull-up values were too high, changed from 10k to 3.3k.
    [grinder_timer.kicad_pcb, grinder_timer.sch]
2020-08-13 Fixed BOM, created pdf of schematic.
    [grinder_timer.sch]
2020-08-20 Fixed TWI pull-ups, switched active and neutral, tidied repo.
    [24x48_digits_font.xlsx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]
2020-08-21 Fixed bug - LED now turns off while grinding.
2020-08-22 Removed gerber export.
2020-08-22 Fixed pull-up resistor values.
    [grinder_timer.sch]
2020-08-22 Call it I2C for consistency.
2020-09-16 Switched from platformio to makefile. Improved/fixed the draw_box function.
2026-06-20 3d-printed bezel for oled.
    [grinder_timer.kicad_pcb, grinder_timer.sch, grinder_timer_bezel.FCStd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]
